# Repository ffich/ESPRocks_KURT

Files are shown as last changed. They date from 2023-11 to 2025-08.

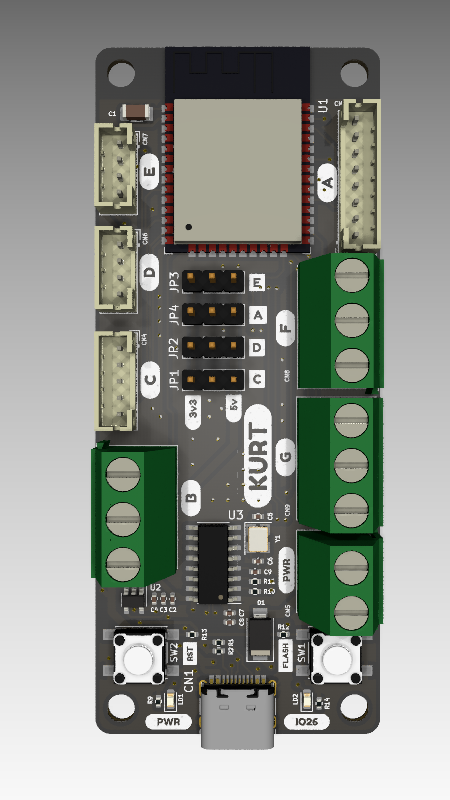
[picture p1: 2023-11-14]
50_3D/ESPRocks_Kurt_Top.png

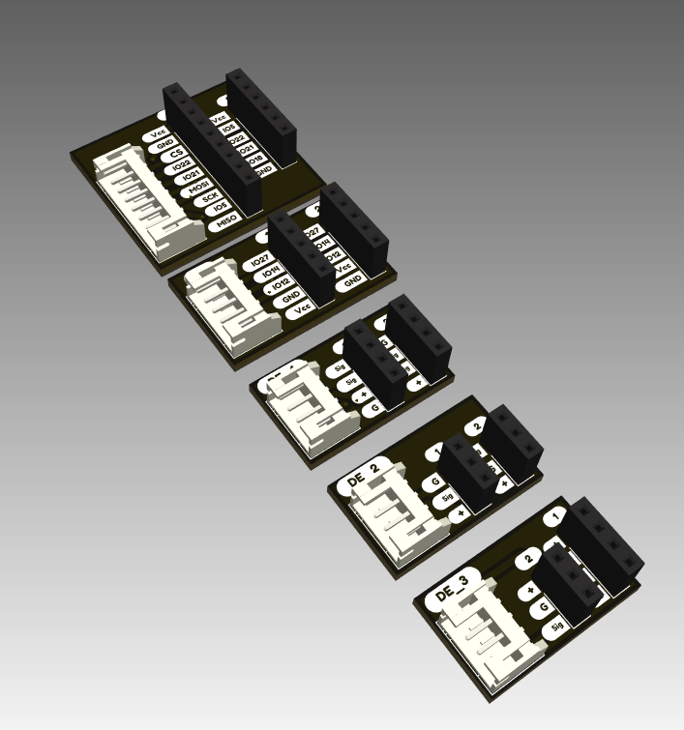
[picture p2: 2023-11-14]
50_3D/ESPRocks_Adapters.png

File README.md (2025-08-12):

# ⚡🐢 ESPRocks KURT — Solder-Free ESP32 Development Board  

# ESPRocks
ESPRocks are Open Source development boards that I designed in collaborartion with [Vincenzo Cacciatore](https://github.com/caccia78). They are based on ESP32 modules designed to help DIY developers to create reliable and flexible home automation systems with ease - with no soldering.

---

## 📖 What is KURT?  

KURT is a **versatile ESP32 development board** that’s:  
- 🧠 **Smart** — Powered by the dual-core Wi-Fi + Bluetooth ESP32 SoC  
- 🔌 **Modular** — Adapter slots for sensors, displays, relays, LEDs, and more  
- 🛡 **Safe** — Foolproof keyed connectors prevent wiring mistakes  
- 🏎 **Fast** — No soldering, no breadboard spaghetti — just plug & play



Fig.1 - Kurt Board



Fig.2 - Adapters

---

## 📦 What’s in the Kit?  

| Icon | Item | Description |
|---|---|---|
| 🐢 | **KURT Board (ESP32)** | The heart of the system — ready for Wi-Fi & Bluetooth projects |
| 🔌 | **4× Adapters** | Connect peripherals in seconds |
| 🪢 | **JST-PH 2.0 Cables** | Secure, tidy wiring |
| 💡 | **Example Peripherals** | Works with buttons, PIRs, OLEDs, relays, WS2812b LEDs & more |



---

## 🚀 Why KURT Rocks  

- 🛠 **No soldering** — Perfect for beginners & fast prototyping  
- 🎯 **Error-proof connectors** — Avoid reversed or wrong wiring  
- ⚡ **Selectable power outputs** — Switch between 3.3 V & 5 V peripherals  
- 🔄 **Hot-swap ready** — Swap modules without rewiring your entire setup  
- 🏠 **IoT-friendly** — Works great with ESPHome & Home Assistant  
- 📖 **Clear labeling** — Easy pinout reading without datasheets  
- 🧹 **Tidy builds** — No messy jumper wires

---

## 🎯 Ideal For  

- 👩‍🔧 Makers & hobbyists who want quick results  
- 🧑‍🏫 Educators teaching IoT & embedded systems  
- 🏠 Smart home DIY projects  
- 🎨 Creative prototypes for events & exhibitions  

---

## 🌐 Try the KURT Configurator  

🔗 **[KURT Online Configurator](https://www.esprocks.it/kurt/configurator)** — Explore supported modules, plan your setup, and get assembly tips with an interactive tool.  

---

## 📂 What’s in This Repo?  

This is the **hardware repository** for KURT:  
- 🗺 **Schematics**  
- 🖼 **PCB layouts**  
- 📋 **BOM** (Bill of Materials)  
- 🖌 **3D models**  

---

## 🏆 Summary  

🐢 **ESPRocks KURT** makes ESP32 prototyping **fun, fast, and frustration-free**.  
Whether you’re building a smart lamp, an interactive art piece, or a home automation sensor — KURT gets you there **without soldering a single wire**.  

---

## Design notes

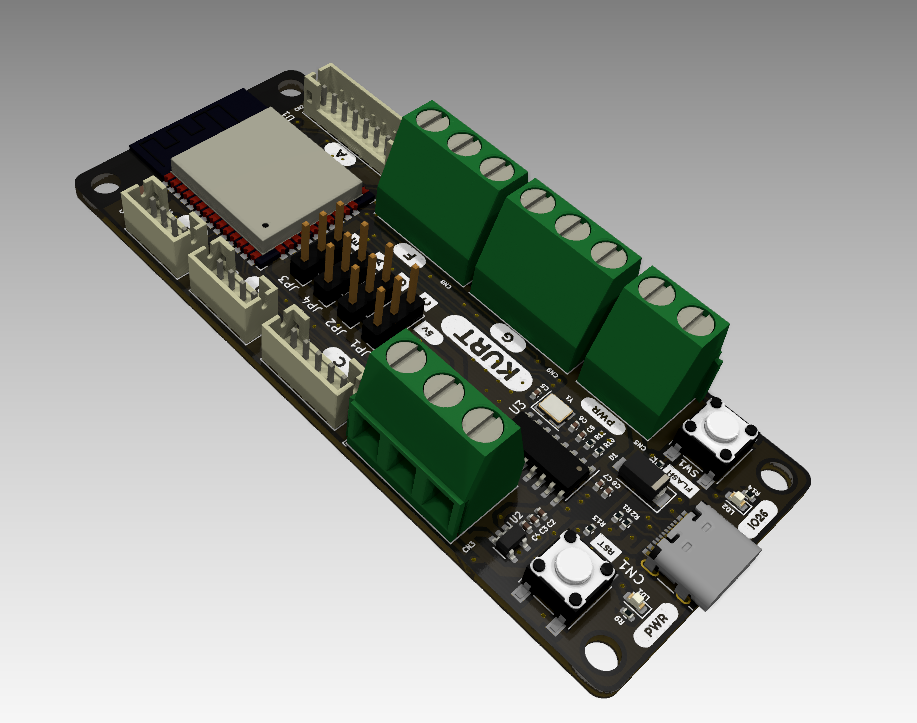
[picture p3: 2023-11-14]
50_3D/ESPRocks_Kurt.png

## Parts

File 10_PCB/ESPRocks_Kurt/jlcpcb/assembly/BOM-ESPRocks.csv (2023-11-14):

Comment | Designator | Footprint | LCSC
1k | R14,R9 | R_0402_1005Metric | C11702
Flash | SW1,SW2 | SW_Push_1P1T_NO_6x6mm_H9.5mm | C127509
D | CN6,CN7 | JST_PH_B4B-PH-K_1x04_P2.00mm_Vertical | C131334
CH340G | U3 | SOIC-16_3.9x9.9mm_P1.27mm | C14267
100uF | C1 | C_1206_3216Metric | C15008
100nF | C8,C9 | C_0402_1005Metric | C1525
470pF | C3 | C_0402_1005Metric | C1537
12pF | C5,C6 | C_0402_1005Metric | C1547
10uF | C4,C7 | C_0402_1005Metric | C15525
A | CN2 | JST_PH_B8B-PH-K_1x08_P2.00mm_Vertical | C157974
C | CN4 | JST_PH_B5B-PH-K_1x05_P2.00mm_Vertical | C157993
USB_C | CN1 | USB_C_Receptacle_HRO_TYPE-C-31-M-12 | C165948
Pwr | LD1 | LED_0603_1608Metric | C2286
User | LD2 | LED_0603_1608Metric | C2288
470 | R10,R11 | R_0402_1005Metric | C25117
10k | R12,R13 | R_0402_1005Metric | C25744
5k1 | R1,R2 | R_0402_1005Metric | C25905
C_Pwr_Jmp | JP1,JP2,JP3,JP4 | PinHeader_1x03_P2.54mm_Vertical | C390679
1uF | C2 | C_0402_1005Metric | C52923
ESP32-WROOM-32E | U1 | ESP32-WROOM-32 | C701342
B | CN3,CN8,CN9 | TerminalBlock_Phoenix_MKDS-1,5-3-5.08_1x03_P5.08mm_Horizontal | C72334
PWR | CN5 | TerminalBlock_Phoenix_MKDS-1,5-2-5.08_1x02_P5.08mm_Horizontal | C8465
SS34 | D1 | D_SMA | C8678
Crystal | Y1 | Crystal_SMD_3225-4Pin_3.2x2.5mm | C9002
SPX3819M5-L-3-3 | U2 | SOT-23-5 | C9055

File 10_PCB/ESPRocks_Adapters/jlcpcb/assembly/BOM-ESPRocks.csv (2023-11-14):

Comment | Designator | Footprint | LCSC
A_Ad_Out_1 | CN14 | PinSocket_1x09_P2.54mm_Vertical | C124417
D_E_Ad_Out_1 | CN20,CN21,CN3 | PinSocket_1x03_P2.54mm_Vertical | C146243
A_Ad_In | CN10 | JST_PH_S8B-PH-K_1x08_P2.00mm_Horizontal | C157915
C_Ad_In | CN11 | JST_PH_S5B-PH-K_1x05_P2.00mm_Horizontal | C157923
D_E_3_Ad_In | CN1,CN12,CN13 | JST_PH_S4B-PH-K_1x04_P2.00mm_Horizontal | C157926
D_E_Ad_Out_1 | CN18,CN19,CN2 | PinSocket_1x04_P2.54mm_Vertical | C2718488
A_Ad_Out_2 | CN15 | PinSocket_1x06_P2.54mm_Vertical | C40877
C_Ad_Out_2 | CN16,CN17 | PinSocket_1x05_P2.54mm_Vertical | C50950

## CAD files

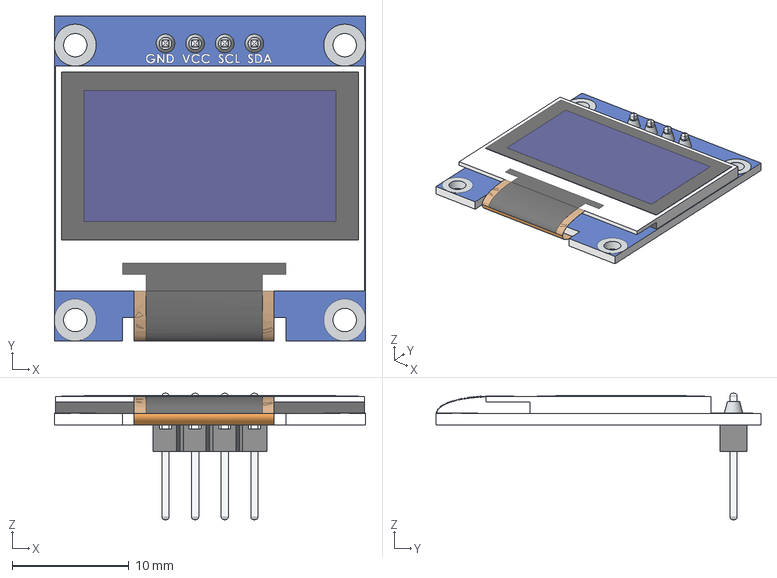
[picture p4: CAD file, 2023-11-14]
60_LIB/3D/OLED-128x64-0.96.step
26.7 x 27.9 x 10.8 mm

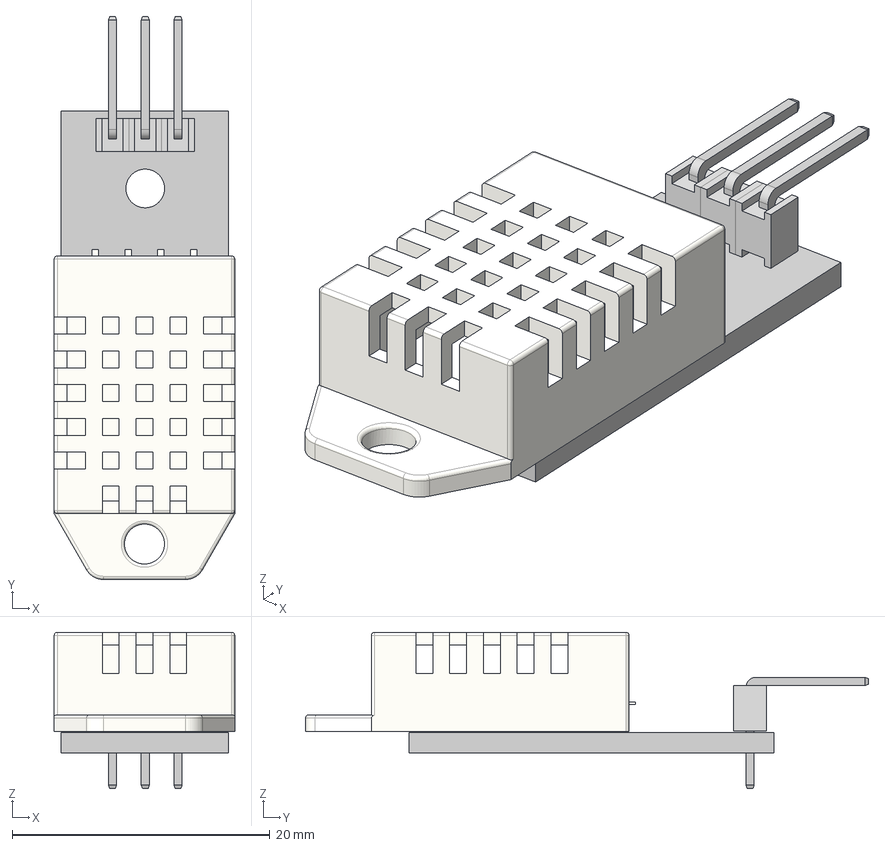
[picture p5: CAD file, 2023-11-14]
60_LIB/3D/DHT22.step
14.0 x 43.7 x 12.1 mm
Right angle 3 pin header
dht22_1

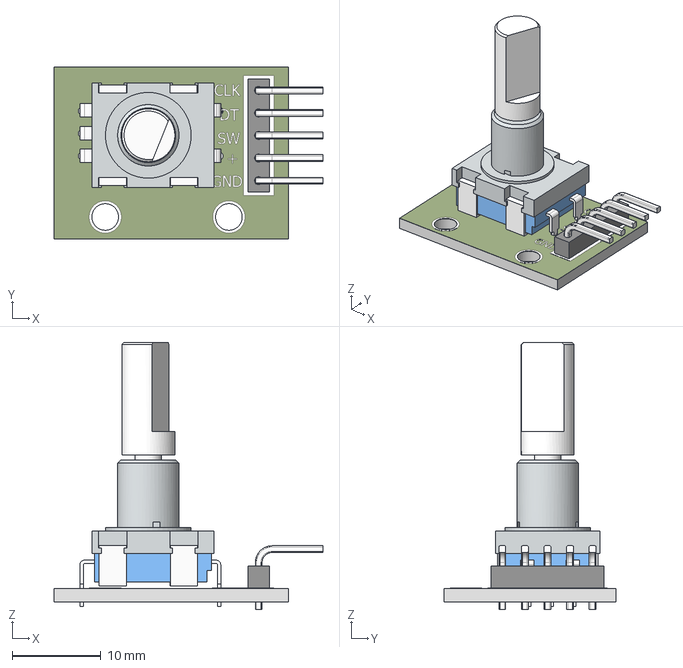
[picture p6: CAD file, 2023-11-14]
60_LIB/3D/rotary encoder_chesr_2013.stp
30.3 x 19.3 x 30.1 mm

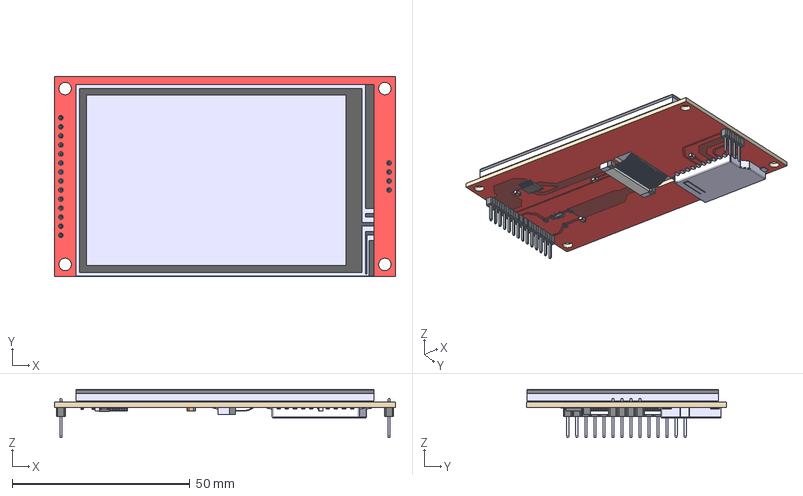
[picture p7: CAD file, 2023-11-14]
60_LIB/3D/ILI9486.stp
96.0 x 56.3 x 13.6 mm
PCB
resistor2 x 4
J3Y
PINx4
PINx14
LCD
ceramic2 x 4
XPT204
SD_holder
Connector

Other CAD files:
60_LIB/3D/2 Ch relay.dwg
60_LIB/3D/ILI9486.stl

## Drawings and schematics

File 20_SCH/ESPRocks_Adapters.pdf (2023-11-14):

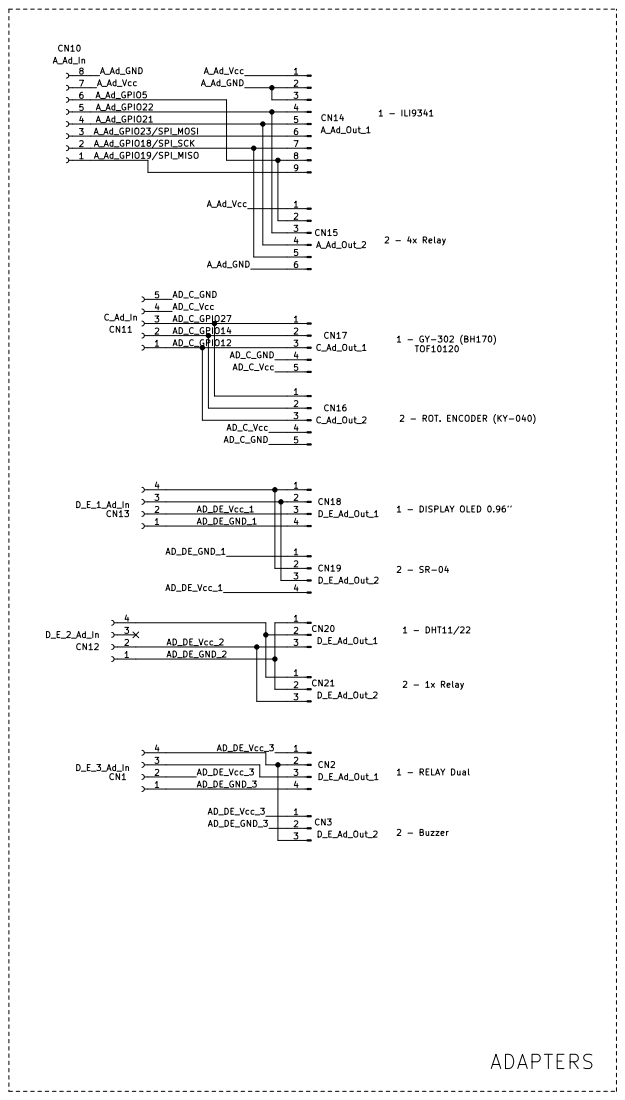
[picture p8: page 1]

A_Ad_GPIO18/SPI_SCK
AD_C_GPIO14 AD_DE_Vcc_3 AD_DE_GND_1 AD_DE_GND_1 AD_DE_GND_2 AD_DE_Vcc_3 AD_C_Vcc AD_C_GND
AD_C_GPIO12 AD_DE_Vcc_1 AD_DE_Vcc_2 AD_DE_Vcc_1
2 - ROT. ENCODER (KY-040) 1 - DISPLAY OLED 0.96'' 1 - RELAY Dual 2 - 1x Relay 1 - DHT11/22

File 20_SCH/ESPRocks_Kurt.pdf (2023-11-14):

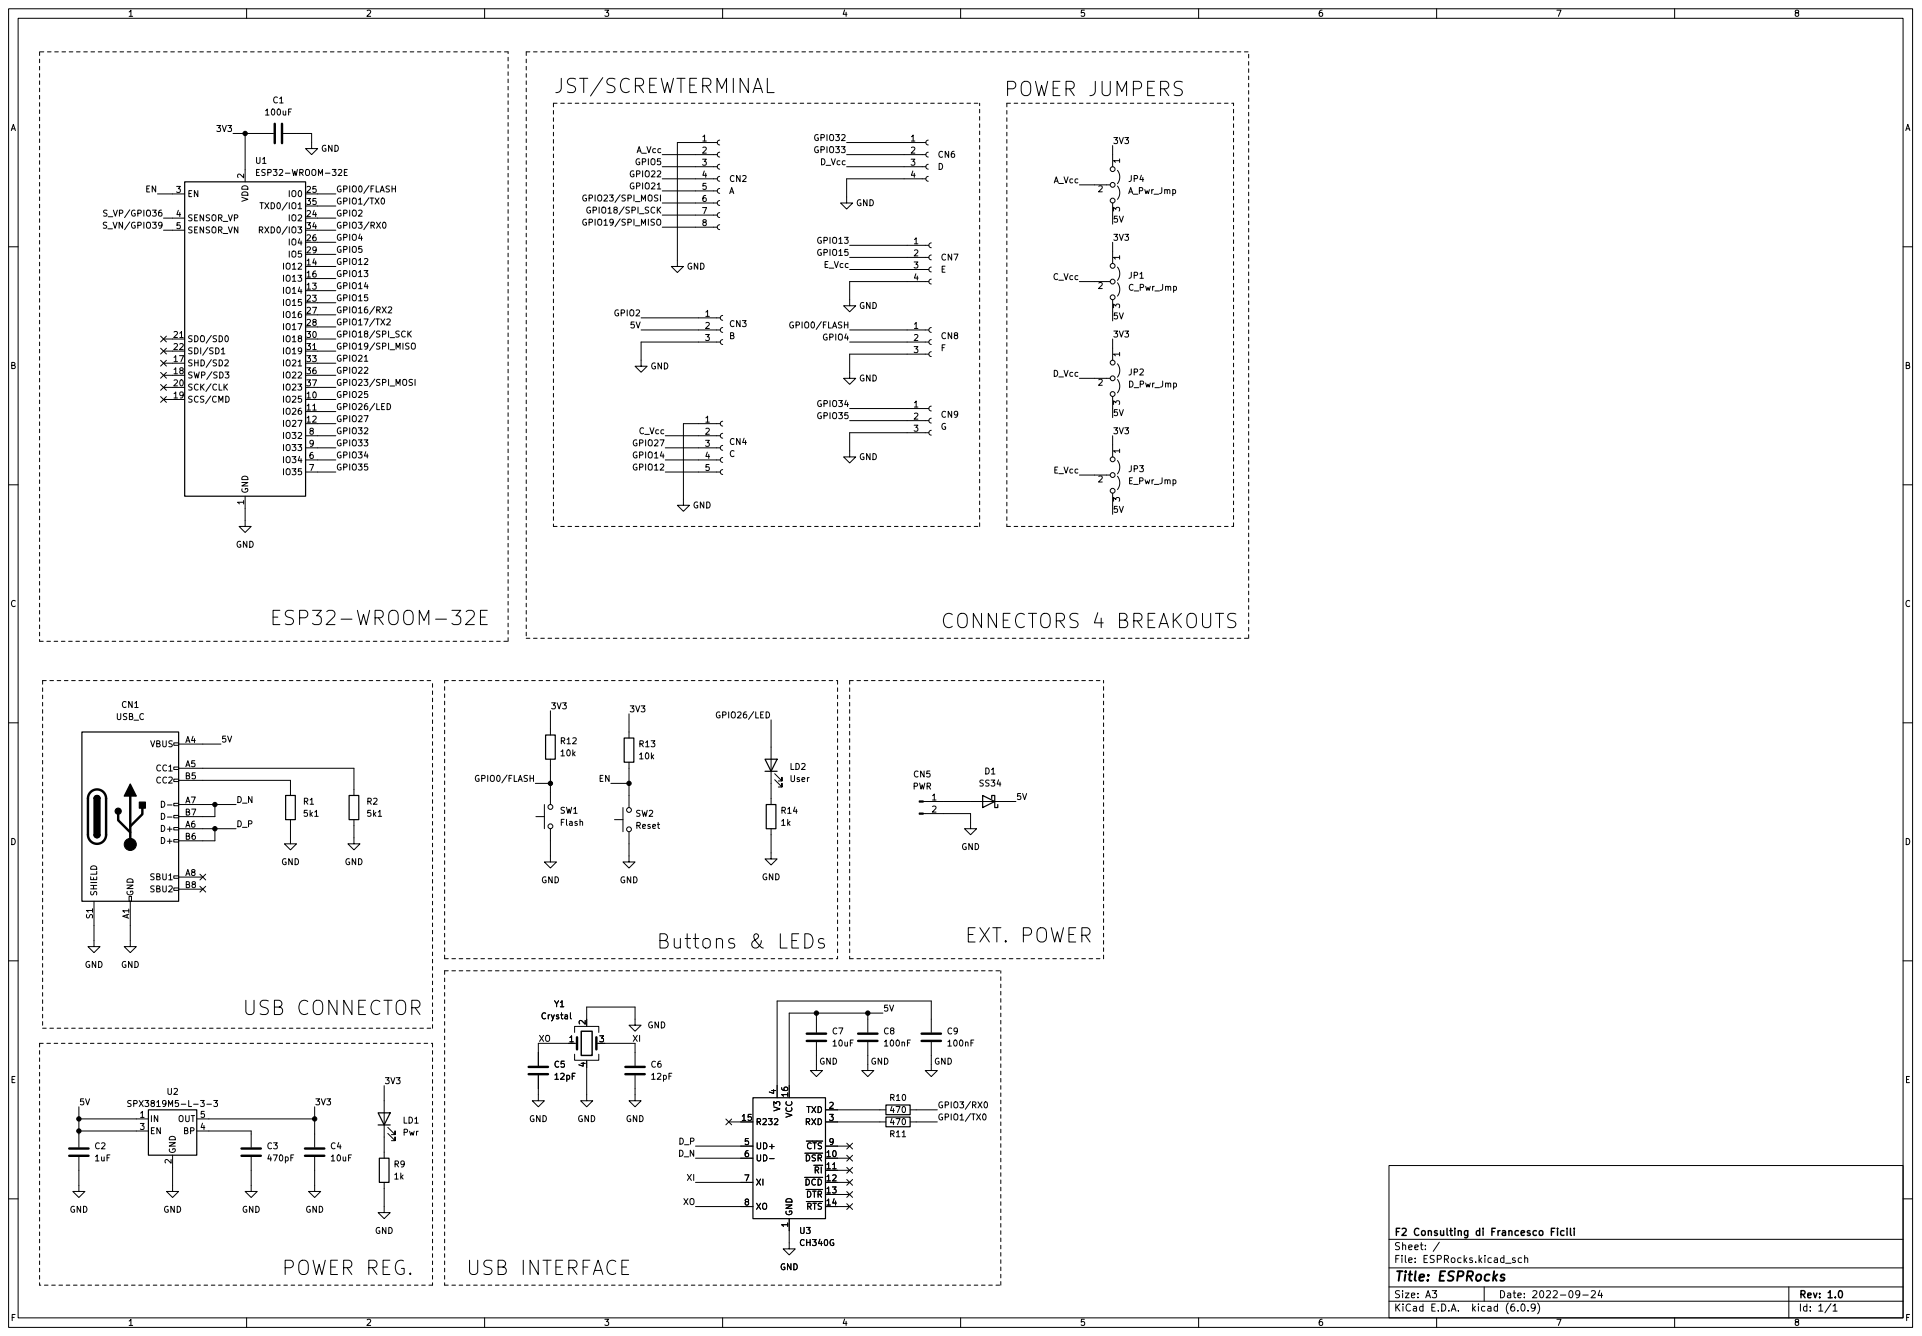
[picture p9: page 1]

2 SCK/CLK 20 SDO/SD0 21 SDI/SD1 22

1 ~{DSR}10 ~{RI}11 ~{DCD}12 ~{DTR}13 ~{RTS}14 R232 15 VCC 16 TXD 2 RXD 3 V3

4 UD+ 5 UD- 6 XI 7 XO 8 ~{CTS} 9 U3CH340G

4 UD+ 5 UD- 6 XI 7 XO 8 ~{CTS} 9 GND

File: ESPRocks.kicad_sch Sheet: / F2 Consulting di Francesco Ficili C2

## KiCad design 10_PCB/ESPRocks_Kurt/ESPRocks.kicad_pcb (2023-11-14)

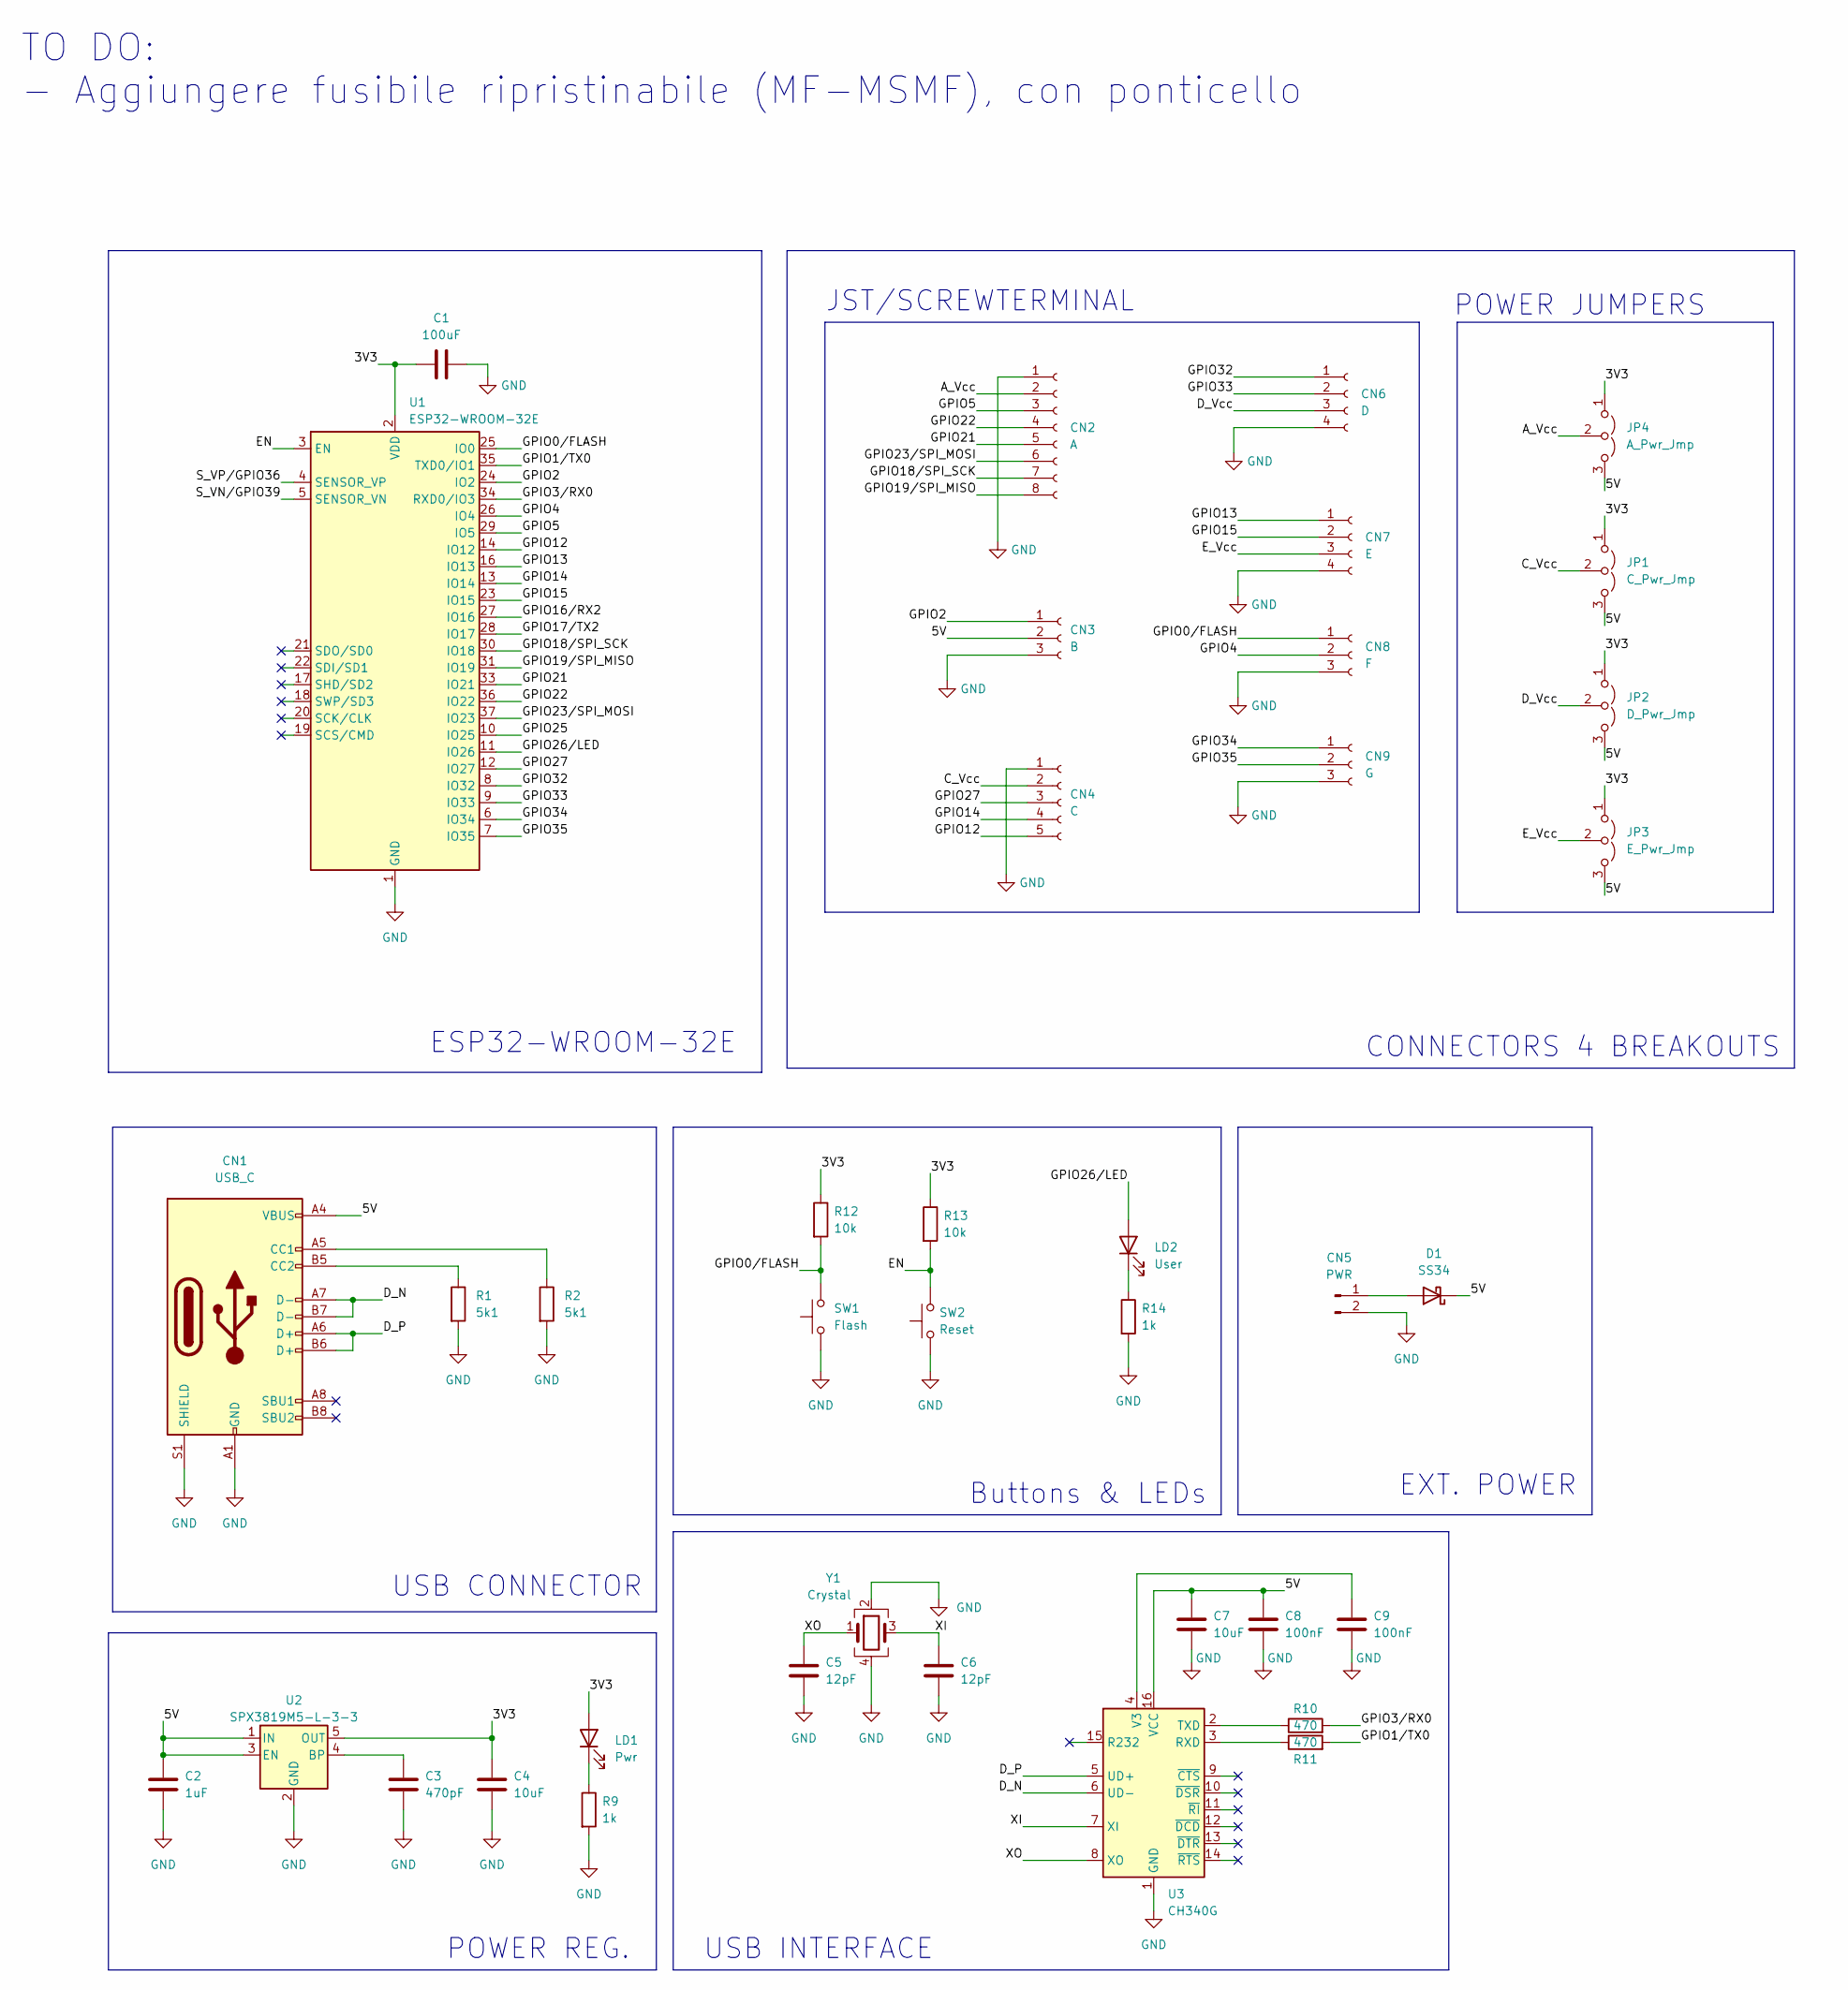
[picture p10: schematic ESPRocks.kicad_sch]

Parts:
C1: 100uF; C_1206_3216Metric; LCSC C15008
C2: 1uF; C_0402_1005Metric; LCSC C52923
C3: 470pF; C_0402_1005Metric; LCSC C1537
C4, C7: 10uF; C_0402_1005Metric; LCSC C15525
C5, C6: 12pF; C_0402_1005Metric; LCSC C1547
C8, C9: 100nF; C_0402_1005Metric; LCSC C1525
CN1: USB_C; USB_C_Receptacle_HRO_TYPE-C-31-M-12; LCSC C165948
CN2: A; JST_PH_B8B-PH-K_1x08_P2.00mm_Vertical; LCSC C157974
CN3: B; TerminalBlock_Phoenix_MKDS-1,5-3-5.08_1x03_P5.08mm_Horizont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; LCSC C72334
CN4: C; JST_PH_B5B-PH-K_1x05_P2.00mm_Vertical; LCSC C157993
CN5: PWR; TerminalBlock_Phoenix_MKDS-1,5-2-5.08_1x02_P5.08mm_Horizont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; LCSC C8465
CN6: D; JST_PH_B4B-PH-K_1x04_P2.00mm_Vertical; LCSC C131334
CN7: E; JST_PH_B4B-PH-K_1x04_P2.00mm_Vertical; LCSC C131334
CN8: F; TerminalBlock_Phoenix_MKDS-1,5-3-5.08_1x03_P5.08mm_Horizont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; LCSC C72334
CN9: G; TerminalBlock_Phoenix_MKDS-1,5-3-5.08_1x03_P5.08mm_Horizont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; LCSC C72334
D1: SS34; D_SMA; LCSC C8678
JP1: C_Pwr_Jmp; PinHeader_1x03_P2.54mm_Vertical; LCSC C390679
JP2: D_Pwr_Jmp; PinHeader_1x03_P2.54mm_Vertical; LCSC C390679
JP3: E_Pwr_Jmp; PinHeader_1x03_P2.54mm_Vertical; LCSC C390679
JP4: A_Pwr_Jmp; PinHeader_1x03_P2.54mm_Vertical; LCSC C390679
LD1: Pwr; LED_0603_1608Metric; LCSC C2286
LD2: User; LED_0603_1608Metric; LCSC C2288
R1, R2: 5k1; R_0402_1005Metric; LCSC C25905
R9, R14: 1k; R_0402_1005Metric; LCSC C11702
R10, R11: 470; R_0402_1005Metric; LCSC C25117
R12, R13: 10k; R_0402_1005Metric; LCSC C25744
SW1: Flash; SW_Push_1P1T_NO_6x6mm_H9.5mm; LCSC C127509
SW2: Reset; SW_Push_1P1T_NO_6x6mm_H9.5mm; LCSC C127509
U1: ESP32-WROOM-32E; ESP32-WROOM-32; LCSC C701342
U2: SPX3819M5-L-3-3; SOT-23-5; LCSC C9055
U3: CH340G; SOIC-16_3.9x9.9mm_P1.27mm; LCSC C14267
Y1: Crystal; Crystal_SMD_3225-4Pin_3.2x2.5mm; LCSC C9002

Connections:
/3V3: C1.1, C4.1, JP1.1 (A), JP2.1 (A), JP3.1 (A), JP4.1 (A), LD1.2 (A), R12.1, R13.1, U1.2 (VDD), U2.5 (OUT)
/5V: C2.1, C7.1, C8.1, CN1.A4 (VBUS), CN1.A9 (VBUS), CN1.B4 (VBUS), CN1.B9 (VBUS), CN3.2, D1.1 (K), JP1.3 (B), JP2.3 (B), JP3.3 (B), JP4.3 (B), U2.1 (IN), U2.3 (EN), U3.16 (VCC)
/A_Vcc: CN2.2, JP4.2 (C)
/C_Vcc: CN4.2, JP1.2 (C)
/D_N: CN1.A7 (D-), CN1.B7 (D-), U3.6 (UD-)
/D_P: CN1.A6 (D+), CN1.B6 (D+), U3.5 (UD+)
/D_Vcc: CN6.3, JP2.2 (C)
/EN: R13.2, SW2.2, U1.3 (EN)
/E_Vcc: CN7.3, JP3.2 (C)
/GPIO0/FLASH: CN8.1, R12.2, SW1.2, U1.25 (IO0)
/GPIO1/TX0: R11.2, U1.35 (TXD0/IO1)
/GPIO2: CN3.1, U1.24 (IO2)
/GPIO3/RX0: R10.2, U1.34 (RXD0/IO3)
/GPIO4: CN8.2, U1.26 (IO4)
/GPIO5: CN2.3, U1.29 (IO5)
/GPIO12: CN4.5, U1.14 (IO12)
/GPIO13: CN7.1, U1.16 (IO13)
/GPIO14: CN4.4, U1.13 (IO14)
/GPIO15: CN7.2, U1.23 (IO15)
/GPIO16/RX2: U1.27 (IO16)
/GPIO17/TX2: U1.28 (IO17)
/GPIO18/SPI_SCK: CN2.7, U1.30 (IO18)
/GPIO19/SPI_MISO: CN2.8, U1.31 (IO19)
/GPIO21: CN2.5, U1.33 (IO21)
/GPIO22: CN2.4, U1.36 (IO22)
/GPIO23/SPI_MOSI: CN2.6, U1.37 (IO23)
/GPIO25: U1.10 (IO25)
/GPIO26/LED: LD2.2 (A), U1.11 (IO26)
/GPIO27: CN4.3, U1.12 (IO27)
/GPIO32: CN6.1, U1.8 (IO32)
/GPIO33: CN6.2, U1.9 (IO33)
/GPIO34: CN9.1, U1.6 (IO34)
/GPIO35: CN9.2, U1.7 (IO35)
/S_VN/GPIO39: U1.5 (SENSOR_VN)
/S_VP/GPIO36: U1.4 (SENSOR_VP)
/XI: C6.1, U3.7 (XI), Y1.3
/XO: C5.1, U3.8 (XO), Y1.1
GND: C1.2, C2.2, C3.2, C4.2, C5.2, C6.2, C7.2, C8.2, C9.2, CN1.A1 (GND), CN1.A12 (GND), CN1.B1 (GND), CN1.B12 (GND), CN1.S1 (SHIELD), CN2.1, CN3.3, CN4.1, CN5.2, CN6.4, CN7.4, CN8.3, CN9.3, R1.2, R2.2, R9.2, R14.2, SW1.1, SW2.1, U1.1 (GND), U1.15 (GND), U1.38 (GND), U1.39 (GND), U2.2 (GND), U3.1 (GND), Y1.2, Y1.4
unnamed: C3.1, U2.4 (BP)
unnamed: C9.1, U3.4 (V3)
unnamed: CN1.A5 (CC1), R2.1
unnamed: CN1.B5 (CC2), R1.1
unnamed: CN5.1, D1.2 (A)
unnamed: LD1.1 (K), R9.1
unnamed: LD2.1 (K), R14.1
unnamed: R10.1, U3.2 (TXD)
unnamed: R11.1, U3.3 (RXD)

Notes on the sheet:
TO DO: - Aggiungere fusibile ripristinabile (MF-MSMF), con ponticello
ESP32-WROOM-32E
Buttons & LEDs
POWER REG.
POWER JUMPERS
USB CONNECTOR
EXT. POWER
USB INTERFACE
JST/SCREWTERMINAL
CONNECTORS 4 BREAKOUTS

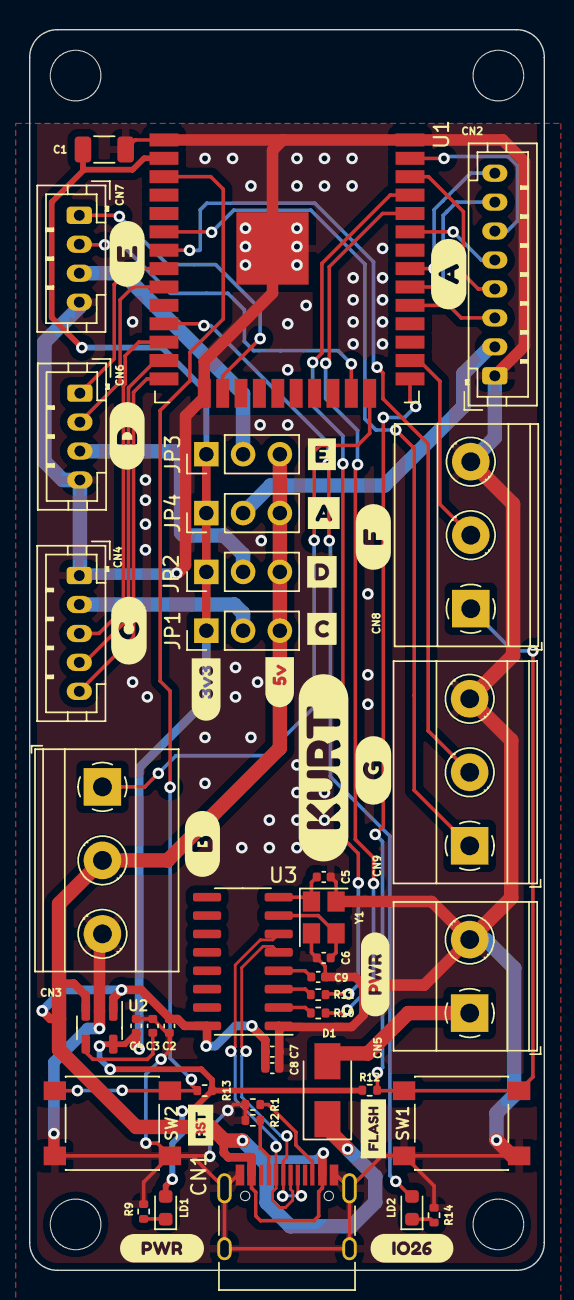
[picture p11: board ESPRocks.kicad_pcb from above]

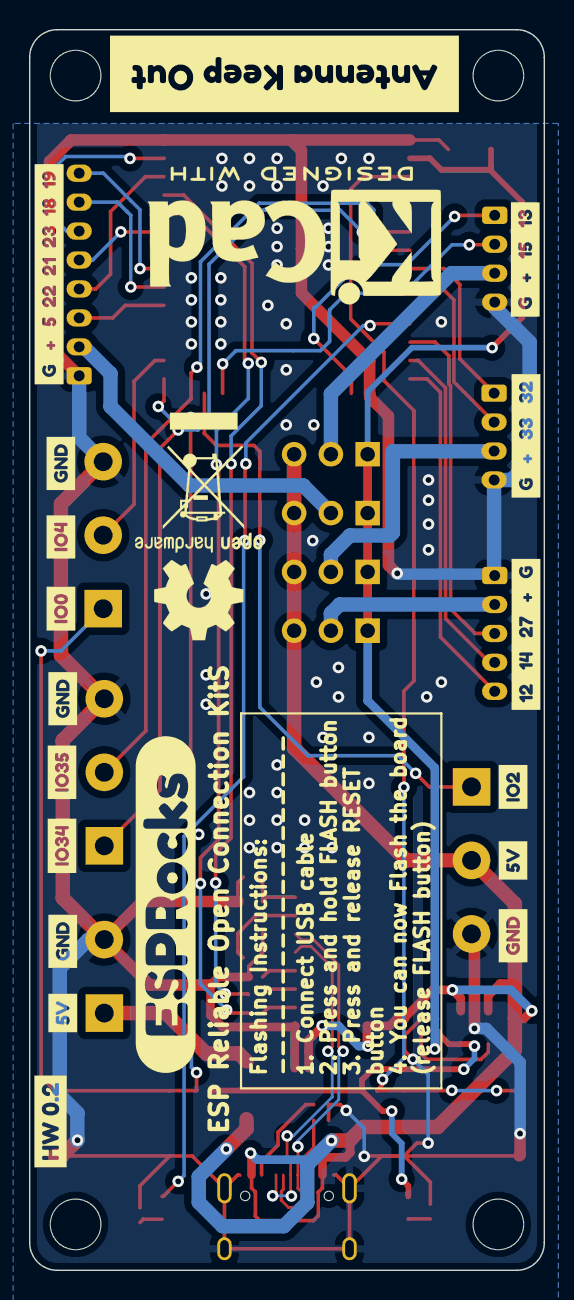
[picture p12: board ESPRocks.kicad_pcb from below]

Board: 2 copper layers, 35.6 x 85.7 mm, 76 parts (18 on the bottom side), 42 nets.

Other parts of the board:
kibuzzard-633DE5EA: G***; kibuzzard-633DE5EA
kibuzzard-633DE5F9: G***; kibuzzard-633DE5F9
kibuzzard-633DE20B: G***; kibuzzard-633DE20B
kibuzzard-633DE216: G***; kibuzzard-633DE216
kibuzzard-633DE730: G***; kibuzzard-633DE730
kibuzzard-633DEAE8: G***; kibuzzard-633DEAE8
kibuzzard-633DEAFD: G***; kibuzzard-633DEAFD
kibuzzard-633DEB42, kibuzzard-633DEB42#2: G***; kibuzzard-633DEB42
kibuzzard-633DEB59, kibuzzard-633DEB59#2, kibuzzard-633DEB59#3, kibuzzard-633DEB59#4: G***; kibuzzard-633DEB59
kibuzzard-633DEB90: G***; kibuzzard-633DEB90
kibuzzard-633DEFBF: G***; kibuzzard-633DEFBF
kibuzzard-633DEFCA: G***; kibuzzard-633DEFCA
kibuzzard-633DEFD9: G***; kibuzzard-633DEFD9
kibuzzard-633DEFE5: G***; kibuzzard-633DEFE5
kibuzzard-633F126E: G***; kibuzzard-633F126E
kibuzzard-633F140C: G***; kibuzzard-633F140C
kibuzzard-633F1259: G***; kibuzzard-633F1259
kibuzzard-633F1449: G***; kibuzzard-633F1449
kibuzzard-635D64EE: G***; kibuzzard-635D64EE
kibuzzard-635D654D: G***; kibuzzard-635D654D
kibuzzard-6341AAF6: G***; kibuzzard-6341AAF6
kibuzzard-6341BAB6: G***; kibuzzard-6341BAB6
kibuzzard-6341BAF6: G***; kibuzzard-6341BAF6
kibuzzard-6341BB0D: G***; kibuzzard-6341BB0D
kibuzzard-6341BB74: G***; kibuzzard-6341BB74
kibuzzard-62924A8F, kibuzzard-62924A8F#2: G***; kibuzzard-62924A8F
kibuzzard-63307F6C: G***; kibuzzard-63307F6C
kibuzzard-63307FA1: G***; kibuzzard-63307FA1
kibuzzard-63307FB0: G***; kibuzzard-63307FB0
kibuzzard-63307FC4: G***; kibuzzard-63307FC4
kibuzzard-63307FD4: G***; kibuzzard-63307FD4
kibuzzard-633080E5: G***; kibuzzard-633080E5

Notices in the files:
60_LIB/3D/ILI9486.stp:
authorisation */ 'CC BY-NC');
